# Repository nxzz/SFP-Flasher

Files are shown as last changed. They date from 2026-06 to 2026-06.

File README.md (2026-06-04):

# sfp-eerom-web

ブラウザ（WebHID）から RP2040(Pico) I2C ゲートウェイ経由で SFP モジュールの EEPROM を読み書きするツール一式。
ダンプ／解析、クローン書込（実シリアル番号を維持）、DWDM 波長設定をブラウザだけで行えます。

```
┌────────────┐   WebHID    ┌──────────────┐    I2C     ┌──────────────┐
│  ブラウザ   │ ─ 64B HID ─ │ RP2040(Pico) │ ─ 0x50/   │  SFP module  │
│ (web/)     │   レポート   │  gateway     │   0x51 ── │  EEPROM      │
└────────────┘             └──────────────┘            └──────────────┘
```

## 構成

| ディレクトリ | 内容 |
|---|---|
| [`web/`](web/) | WebHID Web アプリ（Firebase Hosting にデプロイ）。ダンプ／クローン書込／DWDM 設定。詳細は [`web/README.md`](web/README.md) |
| [`device-src/`](device-src/) | RP2040(Pico) ゲートウェイのファームウェア（PlatformIO / arduino-pico コア） |

## WebHID ⇄ I2C プロトコル

64 バイト固定の HID IN/OUT レポートでコマンドをやり取りする汎用 I2C ゲートウェイです。
2 系統の I2C バスに対応します（bus0 = SDA/SCL = IO12/IO13、bus1 = IO26/IO27）。

OUT レポート（ブラウザ → デバイス, 64B）:

| オフセット | 内容 |
|---|---|
| `[0]` seq | 任意のシーケンス番号（応答にそのままエコー） |
| `[1]` cmd | `0x00` PING / `0x01` READ / `0x02` WRITE / `0x03` SCAN |
| `[2]` bus | 0 or 1 |
| `[3]` addr | 7bit I2C アドレス |
| `[4]` reg | レジスタ／オフセット（READ/WRITE 開始位置） |
| `[5]` len | READ=読み出しバイト数 / WRITE=書き込みバイト数 |
| `[6..]` | WRITE データ |

IN レポート（デバイス → ブラウザ, 64B）:

| オフセット | 内容 |
|---|---|
| `[0]` seq | 要求の seq をエコー |
| `[1]` status | `0x00` OK / `0x01` NACK / `0x02` BADARG / `0x03` TOOBIG |
| `[2]` len | 有効データ長 |
| `[3..]` | データ（READ=読み出し値 / SCAN=見つかったアドレス列 / PING=版数） |

- READ は 1 回最大 61 バイト、WRITE は 1 回最大 58 バイト。
- WRITE は 8 バイトページ境界を跨がないよう Web アプリ側で自動分割します（24Cxx 系 EEPROM 対策）。

## デバイスのビルド／書き込み

[PlatformIO](https://platformio.org/) を使用します（arduino-pico / Earle Philhower コア、USB スタックは Adafruit TinyUSB）。

```bash
cd device-src
pio run                 # ビルド
pio run --target upload  # Pico へ書き込み（BOOTSEL でマウント）
```

## Web アプリの実行

```bash
cd web
npx serve .
#  → 表示された http://localhost:xxxx を Chrome / Edge で開く
```

デプロイ手順や機能の詳細は [`web/README.md`](web/README.md) を参照してください。

## 動作要件

- **Chrome / Edge など Chromium 系ブラウザ**（WebHID 対応。iOS Safari は非対応。Android Chrome は対応）
- RP2040(Pico) ゲートウェイ（`device-src/` のファームウェアを書き込んだもの）

## 注意

クローン書込は SFP の EEPROM を上書きします。先に「ダンプ／解析」でバックアップを取得してください。

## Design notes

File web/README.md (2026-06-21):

# SFP Flash Web

ブラウザ（WebHID）から RP2040(Pico) I2C ゲートウェイ経由で SFP の EEPROM を扱う Web アプリ。
スマートフォンにも対応しています。`device/index.html` の WebHID ⇄ I2C プロトコルがベースです。

## 機能

1. **ダンプ / 解析** — SFP(0x50)から 128B を読み、SFF-8472 として解析表示し、`.bin` で保存（`dump.sh` 相当）
2. **クローン書込（実 SN 維持）** — プリセット or アップロードした `.bin` でモジュールを上書きしつつ、
   そのモジュール本来のシリアル番号(0x44–0x53)を維持。チェックサム自動再計算・アンロック・ベリファイ込み（`modsn.sh` 相当）
   - **自動連続書込** — 挿入待ち→書込→抜去待ちを反復し、差し替えるだけで連続クローン（`loop.sh` 相当）
3. **DWDM 波長設定** — チューナブル SFP の ITU グリッドチャンネルを設定（`set-dwdm-ch.py` 相当）
4. **Avago ISP 書換** — `device-avago-isp` ボード（FW v2.x）で Avago/Broadcom 内蔵 ATmega328 を
   ISP(SPI) 経由で直接読み書きする専用タブ（下記参照）

## Avago ISP 書換（device-avago-isp 専用ボード）

Avago/Broadcom 系モジュールは内部 ATmega が EEPROM を読取専用にエミュレートしており、I2C(0x50)からは
書き込めません（隠し mailbox もプログラミングゲートも存在しない個体がある）。そこで本タブは、
`device-avago-isp` ボード（FW v2.x）を使い、内蔵 ATmega328 の EEPROM を **ISP(SPI シリアルプログラミング)** で
**直接**書き換えます。

- **必須**: 専用ファーム `device-avago-isp`（FW v2.x）＋専用配線
  - MOSI=pin4/GP4, SCK=pin5/GP5, MISO=pin9/GP9, /RESET=pin15/GP15, VCC=pin16/3V3, GND=pin1
- HID コマンド: `0x10` ISP_BEGIN（RESET Low→Programming Enable, 応答=signature） /
  `0x11` ISP_XFER（4バイト ISP 命令を全二重転送） / `0x12` ISP_END（RESET 解放→I2C 復帰）
- タブの操作: ① ISP 接続/デバイス確認（signature・lock・fuse） / ② EEPROM 1KB バックアップ /
  ③ ファーム(フラッシュ)32KB ダンプ（読み出しのみ） /
  ④ A0 クローン書込（内部 EEPROM `0x300–0x37F`, 実SN維持・checksum再計算・verify）
- 書込元像の選び方（プリセット / アップロード / 別バスコピー）は **クローン書込タブと同じ操作感**で、
  ISP タブ内に独立して用意してあります。別バスコピーは I2C を使うので **ISP 開始前**に実行してください。
- 内部 EEPROM レイアウト: `0x300–0x37F` = A0(0x50) ページ（実測確定）
- **Chip Erase は使いません**（フラッシュ＝ファームを消さない）。書込前に必ず ② でバックアップを取得。
  ホスト側 CLI 版は `tools/avr_isp.py`、設計詳細は `AVAGO_ISP_DESIGN.md` を参照。

## プリセットの定義（preset-*.json）

書き込み用 EEPROM 像は書込先モジュール種別ごとに5ファイルで定義します。

- SFP（1G/2G/4G・1000BASE-T 等）: [`preset-sfp.json`](preset-sfp.json)（`bin/` 配下に `.bin`）
- SFP+（8G/10G/16G FC・10GBASE 等）: [`preset-sfp-plus.json`](preset-sfp-plus.json)
- SFP28（25G）: [`preset-sfp28.json`](preset-sfp28.json)
- QSFP / QSFP+（40G・SFF-8636 256B）: [`preset-qsfp.json`](preset-qsfp.json)（`bin/qsfp/` 配下に `.bin`）
- QSFP28（100G）: [`preset-qsfp28.json`](preset-qsfp28.json)（`bin/qsfp/` 配下に `.bin`）

`.bin` を置いてエントリを追記するだけで選択肢が増えます（実 SN は書込時に自動維持されるため、ファイルの SN は
問いません）。読込時、各ファイルのエントリには種別（`form`）が自動付与されます（例 preset-sfp→`SFP`、
preset-qsfp28→`QSFP28`）。

UI の **書込先モジュール**セレクタ（`SFP / SFP+` または `QSFP / QSFP28`）を切り替えると、プリセット一覧が
その種別に対応する `form` のみへ自動で絞り込まれます（SFP 系=SFP/SFP+/SFP28、QSFP 系=QSFP/QSFP28）。
バスも種別に連動します（SFP 系=Bus0、QSFP 系=Bus1）。

```json
{
  "presets": [
    { "name": "Finisar FTLX8571D3BCL (10G SR)", "file": "bin/FTLX8571D3BCL.bin", "note": "10G 850nm SR" }
  ]
}
```

> プリセットは `fetch` で読み込むため `https://` / `http://localhost` が必要です。
> `file://` で直接開いた場合は「アップロード」を使うか、ローカルサーバを起動してください。

### bin を自動で追加する（add-preset.py）

`bin` のパスを渡すと、SFF-8472/8636 を読んで**種別を自動判定** → SFP 系は `bin/`・QSFP 系は `bin/qsfp/` へ
**移動** → ベンダー名/型番を抽出して該当 `preset-*.json` に**追記**します（[`add-preset.py`](add-preset.py)）。

```bash
# 1ファイル（または複数・ワイルドカード）を追加
python add-preset.py /path/to/foo.bin
python add-preset.py *.bin

# 判定だけ確認（移動も書込もしない）
python add-preset.py --dry-run /path/to/foo.bin

# 種別や表示名を手動指定（自動判定を上書き）
python add-preset.py --form SFP+ --name "Cisco FOO-10G" /path/to/foo.bin
```

- 種別自動判定は UI と同一ロジック（識別子＋公称ビットレート＋10G互換ビット）。誤判定時は `--form` で上書き。
- 表示名は既定で「ベンダー 型番」。`--name` で上書き可（複数 bin 指定時は不可）。
- 既に同じ `file` パスが登録済みならスキップします。実 SN は書込時に UI が維持するため bin の SN は問いません。

## 動作要件

- **Chrome / Edge など Chromium 系ブラウザ**（WebHID 対応。iOS Safari は非対応）
- RP2040(Pico) ゲートウェイ（ファーム `device/sfp-gateway.uf2`、プロトコル `device/USB_PROTOCOL.md`）

## ローカル実行

```bash
npx serve .
#  → 表示された http://localhost:xxxx を Chrome で開く
```

## Firebase Hosting へのデプロイ

このディレクトリ（`web/`）がそのままデプロイ単位です。

```bash
npm install -g firebase-tools
firebase login
# .firebaserc の "YOUR_FIREBASE_PROJECT_ID" を実プロジェクト ID に置換してから:
cd web
firebase deploy --only hosting
```

## 注意

- クローン書込は EEPROM を上書きします。先に「ダンプ / 解析」でバックアップを取得してください。
- WRITE は 1 回最大 56 バイト、8 バイトページ境界を跨がないよう自動分割します（24Cxx 系 EEPROM 対策）。

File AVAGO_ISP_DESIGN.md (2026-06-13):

# Avago(AVR内蔵)SFP — Pico経由ISPでEEPROMを書き換える設計

## 0. 背景（検証済みの前提）

I2C(0x50/0x51)経由ではこの個体は書けない、と実機＋ファーム解析で確定済み：

- 対象モジュール: ラベル BROCADE 57-1000117-01 / OEM実体 `AFBR-57D9AMZ-BR1`（= Avago/Broadcom, **ATmega328内蔵**）
- 0x50への書込みは **status=OK でも値が変わらない**（AVRが読取専用エミュレート）。SFFパスワード(0/Finisar)は無効。
- 隠しmailbox `0x58/0x5A` は **NACK**（ハンドラ無効）。有効化条件は内部EEPROM `0x01FF==0x55`（起動時にRAM `0x0336` へ複製、`cpi 0x55` で判定 ＝ ファームで確認済み）。
- ファームに **SPM命令なし** ＝ I2C/シリアルのブートローダ無し。**再書込みはISP(SPI)のみ**。

→ 結論：**内蔵ATmega328のEEPROMをISPで直接書く**。これなら0x55ゲートの鶏卵問題を完全に回避できる。

---

## 1. 全体像

```
                      ┌─ I2Cモード: SFP pin4/5 = SDA/SCL (現状のゲートウェイ)
 Pico (RP2040) ──┤
                      └─ ISPモード: pin4=MOSI pin5=SCK pin9=MISO pin15=RESET (新規)
```

Picoファームに「ISPモード」を追加し、同じUSB-HID(64B)枠でISP用コマンドを足す。
ホスト側(Python)がAVR ISPプロトコルを実装して、EEPROMの吸出し/書込み/照合を行う。

SCK/MOSI は**現状のI2C配線(GPIO12/13)を流用**できる（SFP pin4=SDA=MOSI, pin5=SCL=SCK）。
追加で必要な物理配線は **MISOとRESETの2本だけ**。

---

## 2. 配線（専用ボード: RP2040 ↔ SFPエッジコネクタ）

**VCC/GND 以外は「SFPピン番号 = RP2040 GPIO番号」**で結線した専用ボード。

| 信号 | RP2040 GPIO | SFPピン | 備考 |
|---|---|---|---|
| MOSI | **GP4** | pin4 | I2C bus0 SDA と共用（データ線） |
| SCK  | **GP5** | pin5 | I2C bus0 SCL と共用（クロック線） |
| MISO | **GP9** | pin9 | 入力。成否確認用（無くてもブラインド書込可） |
| /RESET | **GP15** | pin15 | active-low、ISP中ずっとLow |
| VCC 3.3V | 3V3(OUT) | pin16 | モジュール給電 |
| GND | GND | pin1 | コモングラウンド必須 |

> SDA↔MOSI(GP4) / SCL↔SCK(GP5) は役割が一致するので相乗り可。通常時 PB3/PB4/PB5 は
> Hi-Z 入力（ファームで DDRB=0 を確認済み）なので I2C 動作と衝突しない。
> ファームは ISP モードで GP4/5 をビットバングに切替え、ISP_END で I2C(bus0=4/5) に戻す。

ISP突入時は **先にRESETをLow** にしてからSPIを叩く。RESET Lowの間AVRは全ポートをHi-Zにするので、
SCK/MOSIがI2Cプルアップと衝突しない。

---

## 3. ISP突入シーケンス（AVRシリアルプログラミング）

1. SCK = Low（アイドル）にしておく
2. /RESET = Low（GPIO15 Low）
3. 20ms以上待つ
4. **Programming Enable** を送信：`0xAC 0x53 0x00 0x00`
   - 3バイト目の応答エコーが `0x53` なら突入成功。違えばRESETをトグルしてリトライ。
5. 終了時：/RESET = High に戻す（GPIO15開放）→ AVR通常起動 → I2Cに復帰

SCK周波数は **ターゲットクロックの1/4未満**。SFPのAVRは内蔵8MHz想定なので **100–250kHz** で安全側。
Picoのビットバングで十分。

---

## 4. 使うAVR ISPコマンド（4バイト/コマンド, MISO上の応答を読む）

| 操作 | バイト列 | 戻り |
|---|---|---|
| Programming Enable | `AC 53 00 00` | 3バイト目に`53`エコー |
| Read Signature | `30 00 0x 00` (x=0/1/2) | ATmega328=`1E 95 14` / 328P=`1E 95 0F` |
| Read Lock bits | `58 00 00 00` | lockバイト |
| Read Fuse(low/high/ext) | `50 00 00 00` / `58 08 00 00` / `50 08 00 00` | 各fuse |
| **Read EEPROM** 1byte | `A0 00 ad 00` | data（ad=8bit, 1KBなら上位は別途） |
| **Write EEPROM** 1byte | `C0 00 ad dd` | — (書込後 約4ms待つ or RDY/BSYポーリング `F0 00 00 00`) |
| Chip Erase | `AC 80 00 00` | フラッシュ＋EEPROM全消去（**通常は使わない**） |

> ATmega328のEEPROMは1KB(アドレス10bit)。`A0/C0` の上位アドレスビットは2バイト目に載る形式に注意
> （ホスト側で `addr` を 16bit として上位/下位に展開）。バイト単位R/Wで十分（ページ書込みは任意の最適化）。

---

## 5. Picoファーム拡張のインタフェース（device-src/src/main.cpp）

既存の64B HID枠（seq/cmd/...）にISP系を追加。I2Cコマンド(0x00–0x03)はそのまま。

| `cmd` | 名前 | OUT引数 | 動作 / IN応答 |
|---|---|---|---|
| `0x10` | ISP_BEGIN | — | GPIO12/13をWireから切離しSPIビットバングに切替、RESET Low、Programming Enable送信。`data[0]`=成功可否、`data[1..3]`=signature |
| `0x11` | ISP_XFER | `len`=4, `data[6..9]`=4バイト | 4バイトSPIトランザクションを実行し、4バイトの応答を `data[0..3]` で返す（汎用。EEPROM R/Wも全部これで表現） |
| `0x12` | ISP_END | — | RESET High、GPIO12/13をWire(I2C)に復帰 |

設計ポイント：
- **モード排他**：ISP_BEGIN中はI2C(Wire)を `end()`、ISP_END で `Wire.begin()` し直す。GP4/5の機能切替を明示。
- ISP_XFER は薄い「4バイト出して4バイト受ける」だけ。AVR ISPの賢さは全部ホスト側に置く（ファームを単純・汎用に保つ）。
- 速度最適化が要るなら後で `0x13 ISP_READ_EEPROM_BLOCK`（連続n byte吸出し）を足せるが、まずはXFERのみでよい。

---

## 6. ホスト側 Python（tools/avr_isp.py 予定）の責務

`tools/pico_i2c.py` と同じHIDトランスポートを再利用。`Pico` クラスに ISP_BEGIN/XFER/END を足すだけ。

- `enter()/exit()`、`signature()`、`read_lock()/read_fuses()`
- `eeprom_read(addr,n)` / `eeprom_write(addr,bytes)`（XFERの組合せ＋書込後ポーリング）
- `dump_eeprom()` … 1KB全吸出し
- `discover_layout()` … 吸い出したEEPROMと、I2Cで読んだ 0x50/0x51 ダンプ(`pico_i2c.py`)を**バイト照合**して
  「内部EEPROMのどのオフセットが 0x50/0x51 のどこか」を**実測で確定**（下記§7の仮説を裏取り）
- `write_image()` … 改変済み 0x50/0x51 像を対応オフセットへ書込み → 再吸出しでベリファイ → I2C再読込で最終確認

---

## 7. 内部EEPROMレイアウト仮説（ISP吸出しで確定する）

`0x01FF` がゲート＝A2ページ末尾、という事実から：

| 内部EEPROM | I2C側 | 根拠 |
|---|---|---|
| `0x000–0x0FF` | A0 (0x50) 0x00–0xFF | ― |
| `0x100–0x1FF` | A2 (0x51) 0x00–0xFF | `0x1FF`=ゲート=A2末尾と整合 / mailbox 0x5B「128B→A2:0x80-0xFF」とも整合 |
| `0x200–0x3FF` | DDM校正・予備 | ― |

照合で確定後、書きたいのは基本 `0x000–0x0FF`（A0:ベンダ/PN/SN/波長/チェックサム0x3F）と
必要なら `0x100–0x1FF`（A2:0x5F/0x95等チェックサム）。**SN維持クローン**なら 0x44–0x5B を残して上書き。

---

## 8. 作業ワークフロー（実装済み）

1. 専用ボード配線（§2）。pin15→GP15 を RESET として駆動できることを確認。
2. 専用ファームを書込み：`cd device-avago-isp && pio run -t upload`（BOOTSELでマウント）。既存 `device-src` は無改変。
3. `python tools/avr_isp.py` … PING/signature/lock/fuse 確認（ロック時はここで判明）
4. `python tools/avr_isp.py --backup` … EEPROM 1KB全吸出し → `avr_eeprom_backup.bin`（**必須バックアップ**）
5. `python tools/avr_isp.py --set` … `EEPROM[0x01FF]=0x55` を書込み（元値は表示されるので控える）
6. **電源再投入** → `python tools/pico_i2c.py 0` で `0x58` が出れば成功（プログラミングモード）
7. 以降は I2C mailbox(0x58) で EEPROM を読み書き（Web版「Avago Mailbox」タブ or pico_i2c.py 拡張）
8. 仕上げに `0x01FF` を最終値へ（`--restore 0xNN`、またはmailbox）→ 電源再投入で完成

---

## 9. リスクと注意

- **ロックビット**：Cisco/Avago量産品はフラッシュ読出禁止のことあり。ただし `Cisco_AVAGO_10GSC_farm.BIN`(32KB吸出し)が存在＝吸出し元はロック無し。実機もロック無しならEEPROM R/W可。ロック時は §3-4 のsignature/lock読みで判明し、Chip Erase以外で解除不可（Eraseはフラッシュも消える＝モジュール死亡。やらない）。
- **Chip Erase は使わない**（フラッシュ＝AVRファームまで消える）。EEPROMは `C0` で消去不要の上書きが可能。`avr_isp.py` は Chip Erase コマンドを実装していない。
- **必ず先に全EEPROMをバックアップ**（`--backup`）してから書く。
- 電圧は3.3V系で統一。5Vは使わない。
- ISP中はI2C不可（GP4/5を占有）。ISP_BEGIN/ISP_END でフェーズを分ける。
- `avr_isp.py` は既定が**ドライラン**。書込みは `--set` を明示したときだけ。

---

## 10. ファーム & ツール

- **`device-avago-isp/`** … Avago専用ファーム（FW v2.0）。I2Cゲートウェイ＋ISP 3コマンド。**既存 `device-src` は無改変**。
- `tools/avr_isp.py` … ISP ホスト（signature/fuse/lock、EEPROM R/W、`--set`でゲート書込、`--backup`で吸出し）
- `tools/pico_i2c.py` … I2Cダンプ/検証・mailbox前後の確認
- `tools/avr_dis.py` … ファーム逆アセンブラ（ゲート 0x01FF→0x0336 / 0x55 判定の解析に使用済み）

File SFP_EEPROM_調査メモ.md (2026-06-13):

# Avago/Broadcom SFP ファーム解析メモ（avr_flash_dump.bin）

対象: `avr_flash_dump.bin`（32768 byte = 16K word）
目的: i2c から内部 EEPROM を書き換える / **型番(Vendor PN)を変更する**

---

## 1. ハードウェア / ファーム構造（確定）

| 項目 | 結果 |
|---|---|
| MCU | **ATmega328P**（Flash 32KB / 内蔵 EEPROM 1KB） |
| アーキ | `avr-objdump -m avr:5` で正しくデコード（reset = `jmp 0x46fe`） |
| i2c 方式 | **全てビットバンギング**（HW TWI=0xB8–0xBC へのアクセス皆無）。INT0(EIMSK=0x1d/EIFR=0x1c) で SCL 検出 |
| データの真の保管先 | **ATmega328P の内蔵 EEPROM**（avr-libc 標準ドライバを確認） |

### 確認した主要ルーチン
- `0x44c4` = `eeprom_write_byte`（EEARH/EEARL/EEDR→EEMPE→EEPE）
- `0x44d4` / `0x44e4` = `eeprom_read_byte`
- `0x438c` = **i2c マスター書き込み**（start=0x4736, sendbyte=0x419a, ack=0x41e8, stop=0x4224）→ 外部デバイス 0xA0/0xB0 等へ
- `0x4326` = ページ(A2h)シャドウ書き込み API、`0x3cf6` = ホストからの A2h 書き込みハンドラ

### データフロー
```
[ATmega328P 内蔵EEPROM] --(起動/更新時にコピー)--> [外部0xA0 EEPROM = ホストが読むA0h]
        ↑真の保管先                                       ↑被参照コピー
```
内蔵 EEPROM が「正本」。A0h ページは内蔵 EEPROM から書き出される。

---

## 2. 書き込み可否マップ（ホスト i2c 経由）

ホスト書き込みハンドラ(0x3cf6–0x3d96)解析結果：受信バイトは RAM シャドウには反映されるが、
**内蔵 EEPROM への永続化はオフセットを `0x80 ≤ off < 0xF8` でゲート**（`cpi 0x80`/`cpi 0xF8`）。

| 領域 | i2c addr | 書込 | 永続化 | 備考 |
|---|---|---|---|---|
| A2h 0x80–0xF7 | 0x51 | ✅ | ✅ | **ユーザー領域。ノーガードで書ける** |
| A2h 0x00–0x7F / 0xF8–0xFF | 0x51 | △RAMのみ | ❌ | DDM/閾値。リセットで復帰 |
| A0h（ベンダ名/**型番**等） | 0x50 | ホスト書込ハンドラ無し | ❌ | 内蔵EEPROMから書き出される＝実質read-only |

### パスワード
**無し。** SFF-8472 のパスワードオフセット(0x7B–0x7E)比較も4バイトキー照合も存在しない。
ゲートは「オフセット範囲」のみ。

---

## 3. 型番(Vendor PN)変更について ★本命

### 結論: ホスト i2c（前回の選択肢 C 等）では型番は変えられない
- 型番 = **A0h オフセット 0x28–0x37（40–55, 16文字ASCII）** + Rev 0x38–0x3B（SFF-8079）
- 選択肢 C が書けるのは A2h 0x80–0xF7 → **別ページなので無関係**
- A0h にはホスト側スレーブ書込ハンドラが存在しない。仮に外部0xA0 EEPROMを直接書けても、内蔵EEPROMから再コピーされ上書きされる

### 確実な方法: ISP で内蔵 EEPROM を直接書き換える
内蔵 EEPROM → A0h の線形マッピングを確定済み：

> **A0h オフセット N  ↔  内蔵 EEPROM アドレス 0x0300 + N**
> （site1: EEPROM[0x300..0x37F]→A0h[0x00..0x7F]、site2: EEPROM[0x380..0x3FF]→A0h[0x80..0xFF]）

したがって内蔵 EEPROM 上では：

| A0h 内容 | A0h offset | 内蔵EEPROM addr |
|---|---|---|
| Vendor name | 0x14–0x23 | 0x0314–0x0323 |
| **Vendor PN（型番）** | **0x28–0x37** | **0x0328–0x0337** |
| Vendor Rev | 0x38–0x3B | 0x0338–0x033B |
| **CC_BASE チェックサム** | 0x3F | **0x033F** |

#### 手順
```bash
sudo apt install avrdude
# USBasp 等を ATmega328P の ISP端子(MISO/MOSI/SCK/RESET/VCC/GND)へ接続

# 1) バックアップ（必須）
avrdude -c usbasp -p m328p -U eeprom:r:eeprom_backup.bin:r
avrdude -c usbasp -p m328p -U flash:r:flash_backup.bin:r

# 2) eeprom_backup.bin の 0x0328–0x0337 を新しい型番(ASCII, 16byte, 余りは空白0x20)に編集
# 3) CC_BASE 再計算: A0h[0x3F] = (A0h[0x00..0x3E] の総和) & 0xFF
#    = 内蔵EEPROM[0x0300..0x033E] の総和 & 0xFF を [0x033F] に書く
#    ※再計算しないとホスト/NICがモジュールを弾く可能性

# 4) 書き戻し
avrdude -c usbasp -p m328p -U eeprom:w:eeprom_new.bin:r
```
注意: lock bit で保護されていると read/write 不可の場合あり（その時は fuse 確認）。

---

## 4. 実機で i2c 書き込みを試す場合（ユーザー領域のみ）
```bash
sudo apt install i2c-tools
i2cdetect -y <bus>            # 0x50,0x51 確認
i2cdump  -y <bus> 0x51        # バックアップ
i2cset   -y <bus> 0x51 0x80 0xAB   # A2h 0x80–0xF7 のみ永続
i2cget   -y <bus> 0x51 0x80
```

---

## 5. ファーム全体の役割（推定）

reset(0x46fe): SP/フレームポインタ初期化 → 自己チェック(0x4764) → main(0x475e) 無限ループ。
ATmega328P 自身の ADC/USART/SPI は未使用（アナログは外部ICに委譲）。

最頻出コール: `0x438c`(i2cマスター書込) **93回**, `0x44d4`(内蔵EEPROM読) **49回**, 固定小数点演算群(`0x4744`乗算, `0x35c2/0x366a/0x372c`)。

役割まとめ:
1. **ホスト向け i2c スレーブ**(ビットバング, INT0/SCL): A0h/A2h を提供
2. **i2c マスター・オーケストレータ**: 外部アナログ IC を制御
   | 外部addr | 7bit | 回数 | 推定役割 |
   |---|---|---|---|
   | **0xB0** | 0x58 | 96 | アナログ制御IC(レーザ駆動/変調/RX監視)。多数レジスタ設定 |
   | 0xA8 | 0x54 | 12 | 補助デバイス(追加EEPROM/センサ) |
   | 0xA2/0xA0 | 0x51/0x50 | 23/3 | ページEEPROMの被参照コピー書出し |
3. **内蔵EEPROMから較正値読出し** → 0xB0 IC設定 & A0h/A2hページ生成（内蔵EEPROM=正本）
4. **DDM**: 0xB0から温度/電圧/TXbias/TX・RXパワーの生値読込→固定小数点でスケーリング→A2h 0x60-0x6F に書込→閾値比較でアラーム/警告フラグ(0x70+)生成（∴0x00-0x7Fは常時上書き=非永続）
5. **ウォッチドッグ**: `wdr`を98箇所で蹴る

> 一言: **「ホストにSFPとして振る舞うi2cスレーブ」兼「外部アナログIC(0x58)を制御するi2cマスター」で、内蔵EEPROMの較正値でレーザ制御＋DDM監視を行うSFPコントローラ。**

## 6. 改造ファーム：ISP一回で「i2cから型番書換」可能化（実装済み）

方針: **ユーザー領域(A2h 0x80–0xF7)は未使用**なので、そのままの素通しマップで A0h へ振り替える（モードフラグ/コマンド不要、オフセット計算のみ）。

### マッピング
> **A2h(0x51) オフセット (0x80 + k) への i2c 書込 → 内蔵EEPROM[0x300 + k] = A0h[k]**（k=0x00..0x77）

| A0h 内容 | A0h off | 書込先 i2c | (0x51) offset |
|---|---|---|---|
| Vendor name | 0x14–0x23 | 0x51 | 0x94–0xA3 |
| **Vendor PN（型番）** | 0x28–0x37 | 0x51 | **0xA8–0xB7** |
| Vendor Rev | 0x38–0x3B | 0x51 | 0xB8–0xBB |
| **CC_BASE** | 0x3F | 0x51 | **0xBF** |
| CC_EXT | 0x5F | 0x51 | 0xDF |

### パッチ内容（12バイト, `make_patch.py` で生成）
| アドレス | 元 | 改 |
|---|---|---|
| 0x3d80 | `call 0x44c4` | `call 0x4800`（フック） |
| 0x4800 | (空) | `subi r16,0x80` |
| 0x4802 | (空) | `ldi r17,0x03` |
| 0x4804 | (空) | `jmp 0x44c4`（eeprom_write 末尾Jmp） |

出力: `avr_flash_patched.bin`

### 焼き込み（ISP・1回のみ）
```bash
avrdude -c usbasp -p m328p -U flash:r:flash_backup.bin:r     # 退避(必須)
avrdude -c usbasp -p m328p -U eeprom:r:eeprom_backup.bin:r
avrdude -c usbasp -p m328p -U flash:w:avr_flash_patched.bin:r  # 改造ファーム書込
# ※EEPROMは触らない＝現行の型番/較正はそのまま温存
```

### 以降の型番変更（i2cのみ・ISP不要）
1. PN(0x28–0x37, 16byte ASCII, 余りは空白0x20) を i2c 0x51 の 0xA8–0xB7 へ書く
2. **CC_BASE 再計算**: `A0h[0x3F] = Σ A0h[0x00..0x3E] & 0xFF` を 0x51 の 0xBF へ書く（host側で計算）
3. **SFPを抜き挿し（電源再投入）** → 起動時に内蔵EEPROM→A0hが再生成され新型番反映

→ 付属 `recode_pn.sh <bus> "<新型番>"` が PN書込＋CC_BASE再計算を自動化。

### 注意 / フェイルセーフ
- A2h ユーザー領域(0x80–0xF7)は本改造で A0h 編集専用になる（未使用前提）
- CC_BASE 不一致だとホスト/NICがモジュールを弾く可能性 → 必ず再計算
- 失敗しても flash/eeprom バックアップから ISP で復旧可

## 7. 解析環境
- `avr-objdump -D -b binary -m avr:5 avr_flash_dump.bin > fw.asm`
- i2c-tools / avrdude は apt で導入

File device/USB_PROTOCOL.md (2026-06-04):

# SFP EEPROM ゲートウェイ USB / WebHID 仕様書

ブラウザ（WebHID）から Raspberry Pi Pico (RP2040) を経由して、SFP の
I2C EEPROM を読み書きするためのプロトコル仕様。

- ファーム: `c:\Users\netwing\Documents\PlatformIO\Projects\sfp-eeprom-web\src\main.cpp`
- フロント: `index.html`（同フォルダ）
- USB スタック: Adafruit TinyUSB（`-DUSE_TINYUSB`）

---

## 1. USB デバイス構成

複合デバイス（Composite）。

| インタフェース | 用途 |
|---|---|
| **HID**（vendor-defined） | コマンド／応答チャネル（本仕様の対象） |
| **CDC**（仮想シリアル） | デバッグログ出力（115200 bps、任意） |

### HID ディスクリプタ

- レポートディスクリプタ: `TUD_HID_REPORT_DESC_GENERIC_INOUT(64)`
- **Usage Page: `0xFF00`**（ベンダ定義）, Usage: `0x01`
- **Report ID なし**（= レポート ID `0`）
- **Input レポート 64 バイト固定**（デバイス → ホスト）
- **Output レポート 64 バイト固定**（ホスト → デバイス）
- Poll interval: 2 ms

### WebHID からの接続

Usage Page でフィルタするため VID/PID に依存しない。

```js
const devices = await navigator.hid.requestDevice({
  filters: [{ usagePage: 0xFF00 }]
});
const device = devices[0];
await device.open();
device.addEventListener("inputreport", onInputReport);
// 送信は reportId = 0、64バイト固定
await device.sendReport(0, new Uint8Array(64));
```

> WebHID は secure context が必要。`http://localhost` または `https://`、
> および Chrome では `file://` でも利用可能。

---

## 2. レポートフォーマット

すべて 64 バイト固定。未使用領域は `0` 埋め。

### 2.1 OUT（要求）ホスト → デバイス

| オフセット | 名前 | 説明 |
|---|---|---|
| 0 | `seq`  | シーケンス番号。応答にそのまま返る（要求と応答の対応付けに使用） |
| 1 | `cmd`  | コマンド（§3） |
| 2 | `bus`  | I2C バス: `0` or `1`（§4） |
| 3 | `addr` | 7bit I2C アドレス（例: SFP は `0x50` / `0x51`） |
| 4 | `reg`  | レジスタ／オフセット（READ/WRITE の開始位置、0–255） |
| 5 | `len`  | データ長（READ=読み出し数 / WRITE=書き込み数） |
| 6–63 | `data` | WRITE データ（最大 58 バイト） |

### 2.2 IN（応答）デバイス → ホスト

| オフセット | 名前 | 説明 |
|---|---|---|
| 0 | `seq` | 要求の `seq` をエコー |
| 1 | `status` | ステータス（§5） |
| 2 | `len` | 有効データ長 |
| 3–63 | `data` | データ（READ=読み値 / SCAN=検出アドレス列 / PING=版数） |

---

## 3. コマンド

| `cmd` | 名前 | 動作 | 応答 `data` |
|---|---|---|---|
| `0x00` | **PING**  | 疎通確認 | `[0]`=FW major, `[1]`=FW minor（`len`=2） |
| `0x01` | **READ**  | `addr` の `reg` から `len` バイト読む（reg ポインタ書込→read） | 読み出しバイト列（`len` バイト） |
| `0x02` | **WRITE** | `addr` の `reg` から `data` を `len` バイト書く | なし（`len`=0） |
| `0x03` | **SCAN**  | `bus` 上の `0x08`–`0x77` を走査 | 検出アドレス列（`len`=件数） |

### 動作詳細

- **READ**: `beginTransmission(addr) → write(reg) → endTransmission(STOP) → requestFrom(addr,len)`。
  指定数を取得できなければ `NACK`。
- **WRITE**: `beginTransmission(addr) → write(reg) → write(data...) → endTransmission(STOP)`。
  完了後 **6 ms** 待つ（EEPROM 書き込みサイクル対策。レジスタ系デバイスには無害）。
- **SCAN**: 各アドレスへ空トランザクションを送り、ACK が返ったものを列挙。

---

## 4. バス割り当て（RP2040）

| `bus` | ペリフェラル | コード | SDA | SCL |
|---|---|---|-----|-----|
| `0` | i2c0 | `Wire`  | GPIO12 | GPIO13 |
| `1` | i2c1 | `Wire1` | GPIO26 | GPIO27 |

クロック: 両バスとも 100 kHz。

---

## 5. ステータスコード

| 値 | 名前 | 意味 |
|----|---|---|
| `0x00` | OK | 成功 |
| `0x01` | NACK | デバイス無応答 / 期待バイト数に届かず |
| `0x02` | BADARG | 不正な引数（例: `bus > 1`） |
| `0x03` | TOOBIG | `len` が上限超過 |

---

## 6. サイズ上限と分割

| 項目 | 値 | 由来 |
|---|-----|---|
| 1 回の READ 最大 | **61 バイト** | `64 − 3`（応答ヘッダ） |
| 1 回の WRITE 最大 | **58 バイト** | `64 − 6`（要求ヘッダ） |

フロント側（`index.html`）の実装上限と分割方針:

- READ: **60 バイト/回**でチャンク分割し、`reg` を進めて連結。
- WRITE: **56 バイト/回** かつ **8 バイトページ境界**を跨がないよう分割
  （24Cxx 系 EEPROM のページ書き込み対策）。

`reg` は 8bit のため **オフセットは 0–255**。SFP の 256 バイトページ内で完結する。
A0h（0x50）/ A2h（0x51）のページ切替が要る場合はアドレス自体を変える。

---

## 7. 通信シーケンス例

### PING
```
OUT: seq=01 cmd=00 ...
IN : seq=01 status=00 len=02 data=[01 00]   // FW v1.0
```

### SFP 基本情報を 16 バイト読む（0x50, offset 0x14 = Vendor name 先頭）
```
OUT: seq=02 cmd=01 bus=00 addr=50 reg=14 len=10
IN : seq=02 status=00 len=10 data=[... ASCII ...]
```

### 1 バイト書き込み（0x50, offset 0x7F に 0xAB）
```
OUT: seq=03 cmd=02 bus=00 addr=50 reg=7F len=01 data=[AB]
IN : seq=03 status=00 len=00
```

### バススキャン（bus0）
```
OUT: seq=04 cmd=03 bus=00 ...
IN : seq=04 status=00 len=02 data=[50 51]    // 0x50, 0x51 検出
```

---

## 8. 注意事項

- ホストは **1 要求 → 1 応答** を直列に行うこと。ファームは応答未送信中の新規
  OUT レポートを無視する（単一スロット）。
- 応答タイムアウトはフロント側で 2000 ms 推奨。
- SFP の EEPROM は書き込み保護領域・パスワード保護領域がある場合がある
  （A0h の一部、A2h の制御/パスワード領域など）。WRITE 失敗時は `NACK` が返る。

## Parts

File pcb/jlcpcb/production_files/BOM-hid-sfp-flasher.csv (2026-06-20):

Comment | Designator | Footprint | LCSC | Quantity
0.1u | C10,C11,C12,C13,C14,C15,C16,C18,C3,C6,C7 | C_0402_1005Metric | C1525 | 11
10k | R17,R18,R19,R20 | R_0402_1005Metric | C25744 | 4
10u | C5 | C_0603_1608Metric | C19702 | 1
15k | R6 | R_0603_1608Metric | C22809 | 1
1k | R7,R8 | R_0402_1005Metric | C11702 | 2
1u | C8,C9 | C_0402_1005Metric | C52923 | 2
2.2u 3A | L1 | CMLW4030S2R2MST | C431273 | 1
30pF | C1,C2 | C_0603_1608Metric | C1658 | 2
33 | R3,R4 | R_0402_1005Metric | C25105 | 2
4.7u | C4 | C_0603_1608Metric | C19666 | 1
5.1k | R1,R2 | R_0402_1005Metric | C25905 | 2
68k | R5 | R_0603_1608Metric | C23231 | 1
HC-TYPE-C-16P-01A-O | USB1 | USB-C-SMD_G-SWITCH_GT-USB-7010EN | C2997434 | 1
PSRV05-4MR6T1G | D1 | SOT-23-6_L2.9-W1.6-P0.95-LS2.8-BL | C2936987 | 1
QSFP28 38PIN 49091-01M311 | U4 | CONN-SMD_38P-P0.80_TE_1551920-2 | C50159077 | 1
RESET | SW2 | SW_SPST_PTS810 | C470427 | 1
RP2040 | U1 | LQFN-56_L7.0-W7.0-P0.4-EP | C2040 | 1
SFP+ | J1 | SFP20P | C42418480 | 1
SMD-3225_4P12M20PF10PPM | X1 | CRYSTAL-SMD_4P-L3.2-W2.5-BL | C133334 | 1
SMD0805B050TF | F1 | F0805 | C269104 | 1
TLV62569DBV | U3 | SOT-23-5 | C141836 | 1
USB_BOOT | SW1 | SW_SPST_PTS810 | C470427 | 1
W25Q16JVUXIQ | U2 | USON-8_L3.0-W2.0-P0.50-BL-EP | C2843335 | 1

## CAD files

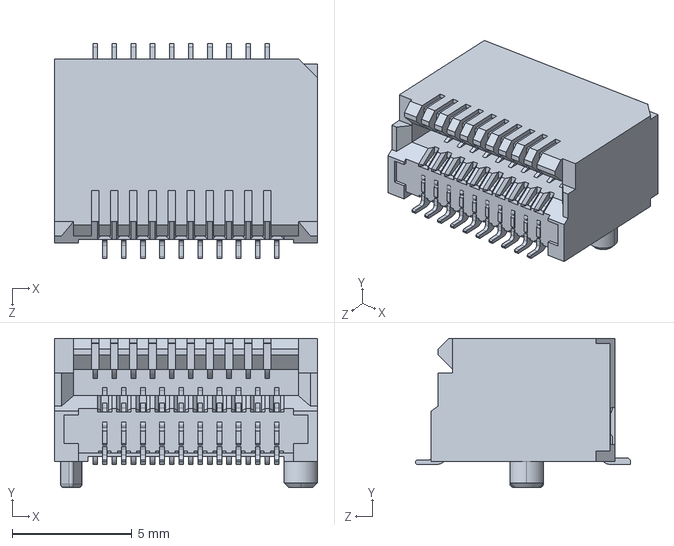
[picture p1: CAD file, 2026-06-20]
pcb/SFP20P/SFP20P SFP&SFP &SFP28 1X1连接器 模型3D.STEP
11.0 x 6.25 x 8.99 mm

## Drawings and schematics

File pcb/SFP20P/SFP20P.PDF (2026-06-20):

### MECHANICAL DIMENSION

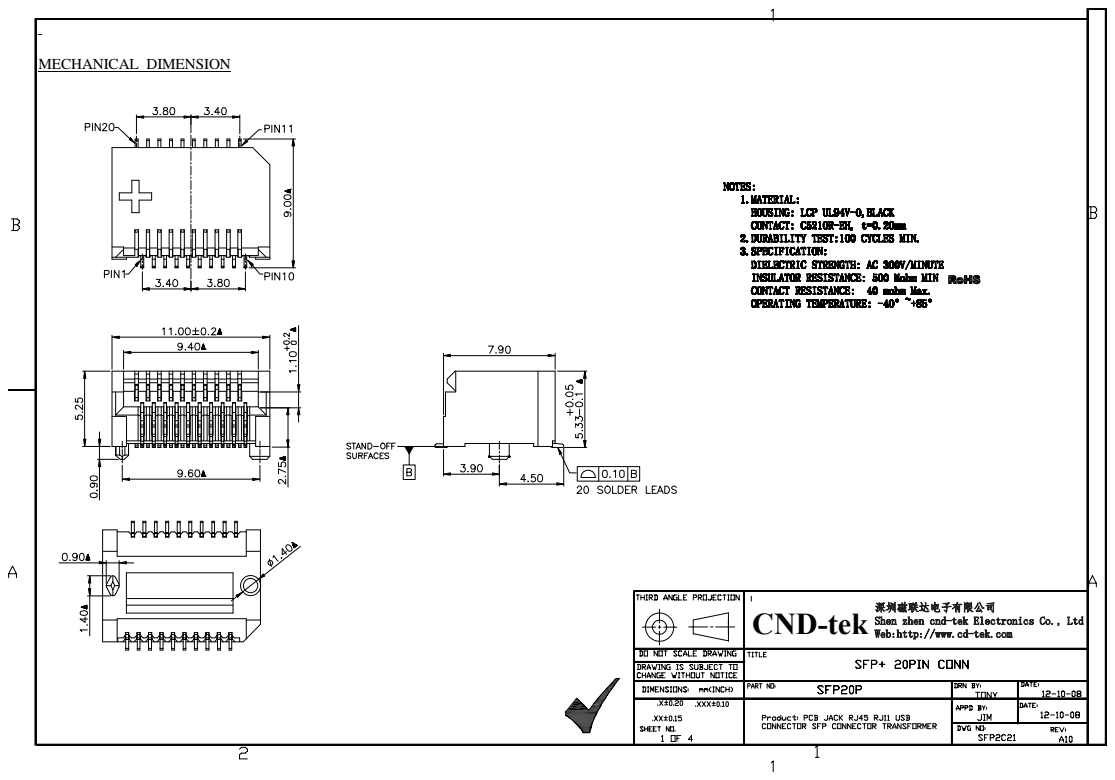
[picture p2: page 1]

深圳磁联达电子有限公司 Shen zhen cnd-tek Electronics Co., Ltd CND-tek Web:http://www.cd-tek.com

SFP+ 20PIN CONN
SFP20P

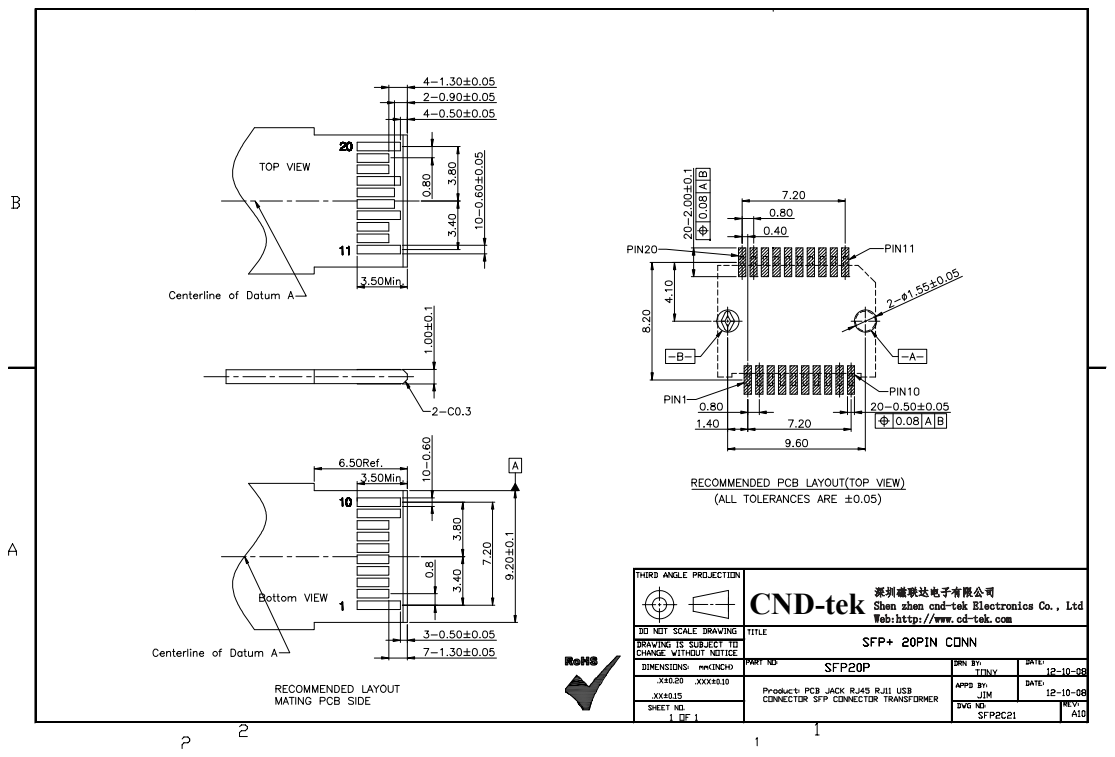
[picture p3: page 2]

Shen zhen cnd-tek Electronics Co., Ltd CND-tek Web:http://www.cd-tek.com 深圳磁联达电子有限公司

SFP+ 20PIN CONN
SFP20P

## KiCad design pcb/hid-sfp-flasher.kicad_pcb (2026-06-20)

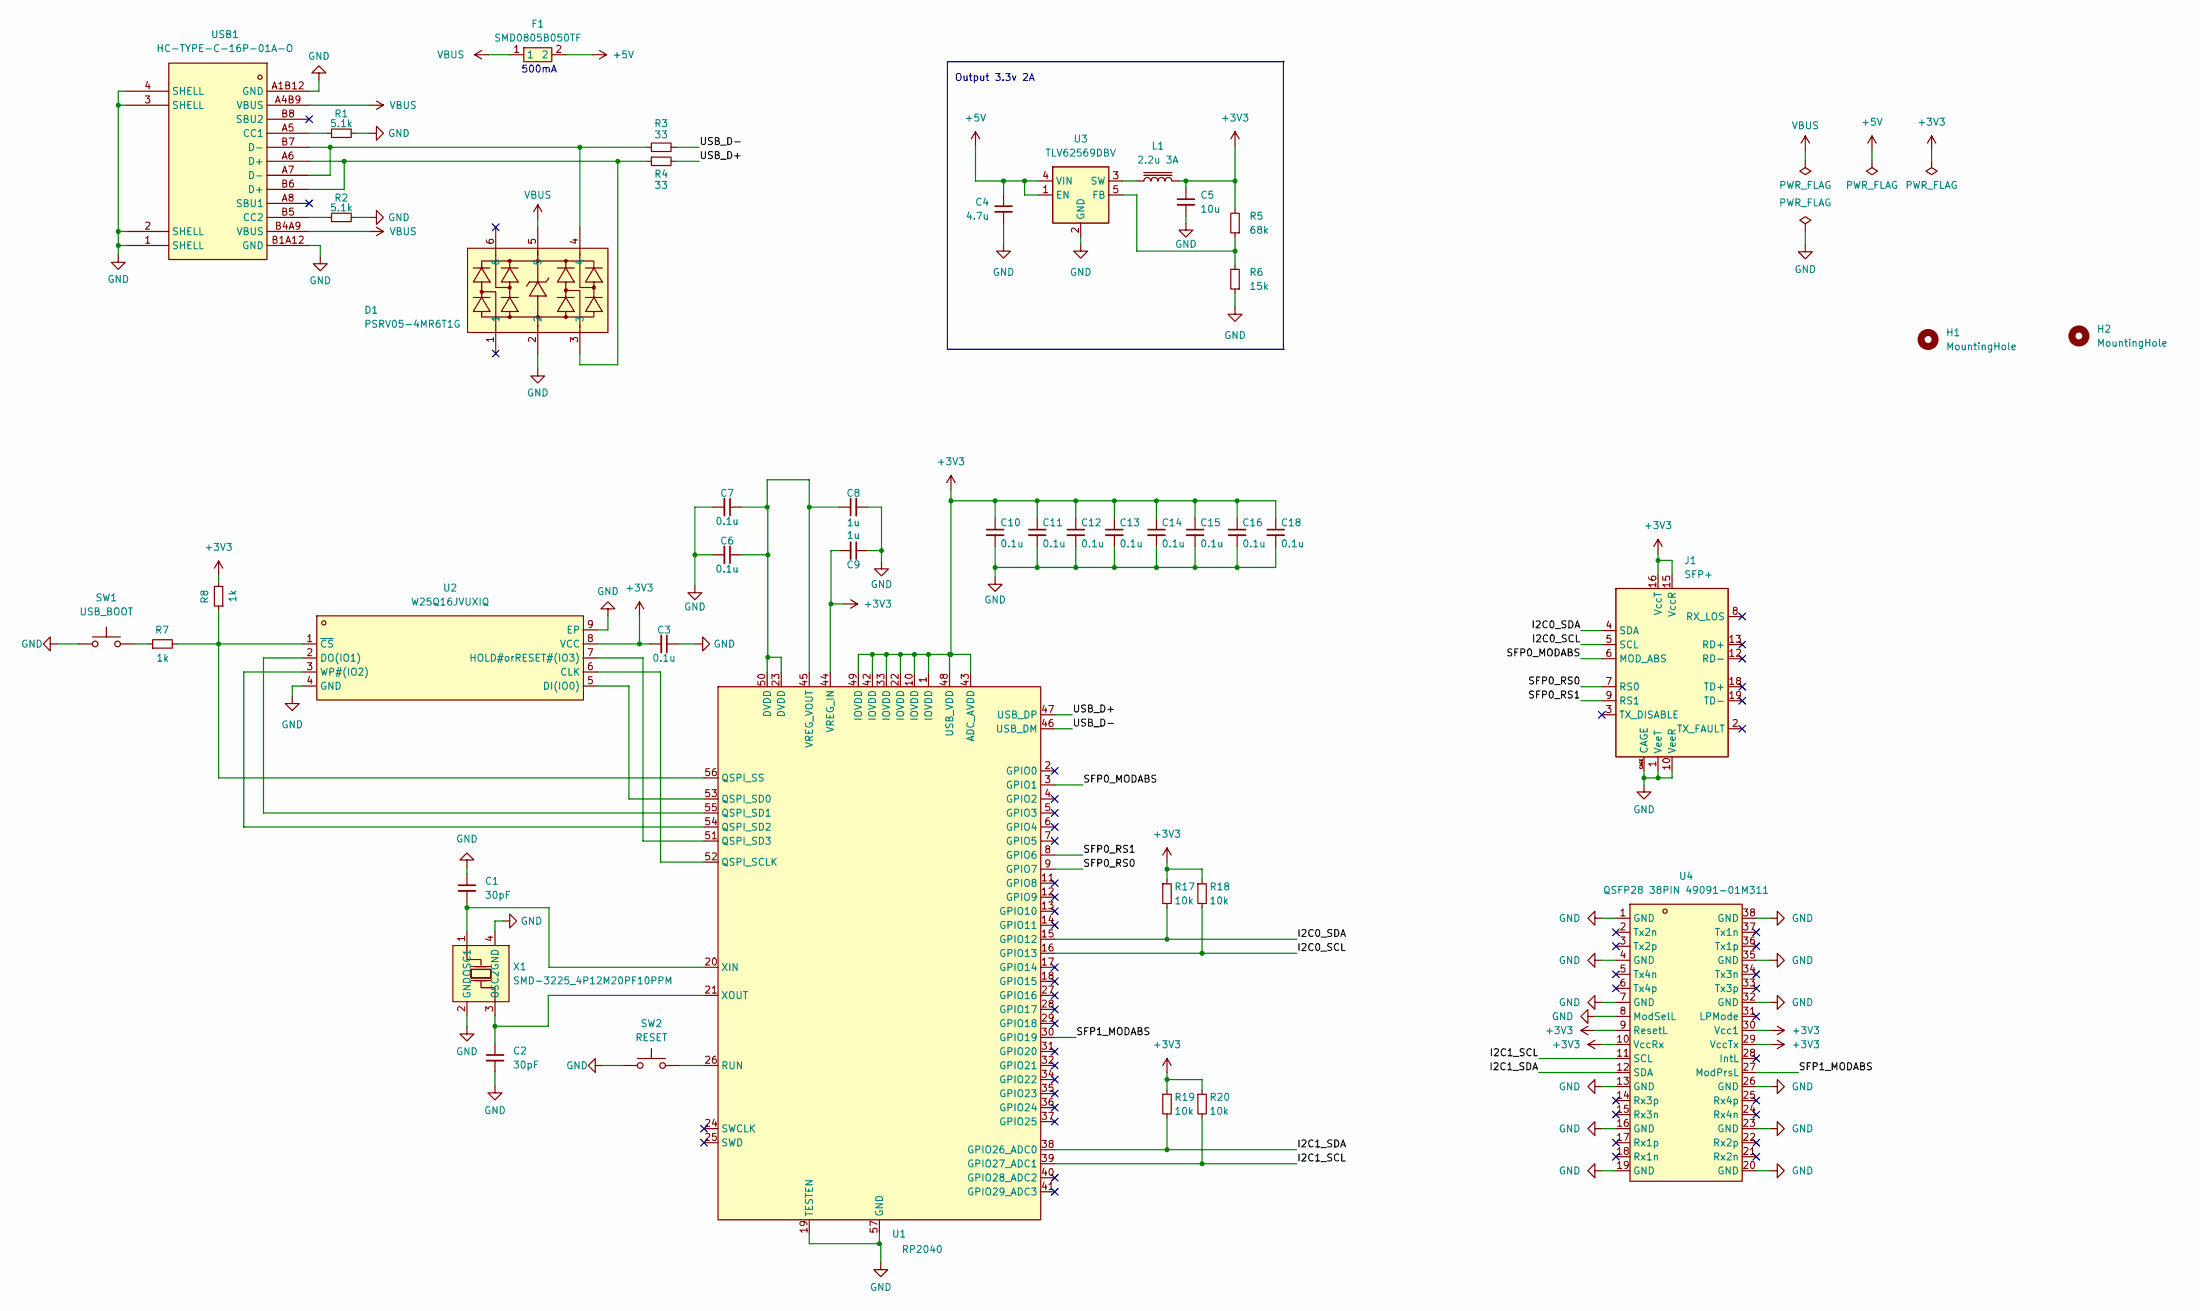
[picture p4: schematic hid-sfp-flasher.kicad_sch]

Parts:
C1, C2: 30pF; C_0603_1608Metric; LCSC Part C1658
C3, C6, C7, C10, C11, C12, C13, C14, C15, C16, C18: 0.1u; C_0402_1005Metric; LCSC Part C1525
C4: 4.7u; C_0603_1608Metric; LCSC C19666
C5: 10u; C_0603_1608Metric; LCSC C19702
C8, C9: 1u; C_0402_1005Metric; LCSC C52923
D1: PSRV05-4MR6T1G; SOT-23-6_L2.9-W1.6-P0.95-LS2.8-BL; LCSC Part C2936987
F1: SMD0805B050TF; F0805; LCSC Part C269104
H1, H2: MountingHole; MountingHole_3.2mm_M3
J1: SFP+; SFP20P
L1: 2.2u 3A; CMLW4030S2R2MST; LCSC C431273
R1, R2: 5.1k; R_0402_1005Metric; LCSC Part C25905
R3, R4: 33; R_0402_1005Metric; LCSC Part C25105
R5: 68k; R_0603_1608Metric; LCSC C23231
R6: 15k; R_0603_1608Metric; LCSC C22809
R7, R8: 1k; R_0402_1005Metric; LCSC C11702
R17, R18, R19, R20: 10k; R_0402_1005Metric; LCSC C25744
SW1: USB_BOOT; SW_SPST_PTS810; LCSC C470427
SW2: RESET; SW_SPST_PTS810; LCSC C470427
U1: RP2040; LQFN-56_L7.0-W7.0-P0.4-EP; LCSC Part C2040
U2: W25Q16JVUXIQ; USON-8_L3.0-W2.0-P0.50-BL-EP; LCSC Part C2843335
U3: TLV62569DBV; SOT-23-5; LCSC C141836
U4: QSFP28 38PIN 49091-01M311; CONN-SMD_38P-P0.80_TE_1551920-2; MPN QSFP28 38PIN 49091-01M311; LCSC Part C50159077
USB1: HC-TYPE-C-16P-01A-O; USB-C-SMD_G-SWITCH_GT-USB-7010EN; LCSC Part C2997434
X1: SMD-3225_4P12M20PF10PPM; CRYSTAL-SMD_4P-L3.2-W2.5-BL; LCSC Part C133334

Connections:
+3V3: C3.2, C5.1, C9.2, C10.1, C11.1, C12.1, C13.1, C14.1, C15.1, C16.1, C18.1, J1.15 (VccR), J1.16 (VccT), L1.2, R5.2, R8.2, R17.1, R18.1, R19.1, R20.1, U1.1 (IOVDD), U1.10 (IOVDD), U1.22 (IOVDD), U1.33 (IOVDD), U1.42 (IOVDD), U1.43 (ADC_AVDD), U1.44 (VREG_IN), U1.48 (USB_VDD), U1.49 (IOVDD), U2.8 (VCC), U4.9 (ResetL), U4.10 (VccRx), U4.29 (VccTx), U4.30 (Vcc1)
+5V: C4.1, F1.2, U3.1 (EN), U3.4 (VIN)
/I2C0_SCL: J1.5 (SCL), R18.2, U1.16 (GPIO13)
/I2C0_SDA: J1.4 (SDA), R17.2, U1.15 (GPIO12)
/I2C1_SCL: R20.2, U1.39 (GPIO27_ADC1), U4.11 (SCL)
/I2C1_SDA: R19.2, U1.38 (GPIO26_ADC0), U4.12 (SDA)
/SFP0_MODABS: J1.6 (MOD_ABS), U1.3 (GPIO1)
/SFP0_RS0: J1.7 (RS0), U1.9 (GPIO7)
/SFP0_RS1: J1.9 (RS1), U1.8 (GPIO6)
/SFP1_MODABS: U1.30 (GPIO19), U4.27 (ModPrsL)
/USB_D+: R4.2, U1.47 (USB_DP)
/USB_D-: R3.2, U1.46 (USB_DM)
GND: C1.1, C2.2, C3.1, C4.2, C5.2, C6.2, C7.2, C8.2, C9.1, C10.2, C11.2, C12.2, C13.2, C14.2, C15.2, C16.2, C18.2, D1.2, J1.1 (VeeT), J1.10 (VeeR), J1.11 (VeeR), J1.14 (VeeR), J1.17 (VeeT), J1.20 (VeeT), J1.CAGE, R1.2, R2.2, R6.1, SW1.2, SW2.2, U1.19 (TESTEN), U1.57 (GND), U2.4 (GND), U2.9 (EP), U3.2 (GND), U4.1 (GND), U4.4 (GND), U4.7 (GND), U4.8 (ModSelL), U4.13 (GND), U4.16 (GND), U4.19 (GND), U4.20 (GND), U4.23 (GND), U4.26 (GND), U4.32 (GND), U4.35 (GND), U4.38 (GND), USB1.1 (SHELL), USB1.2 (SHELL), USB1.3 (SHELL), USB1.4 (SHELL), USB1.A1B12 (GND), USB1.B1A12 (GND), X1.2 (GND), X1.4 (GND)
unnamed: D1.3, R4.1, USB1.A6 (D+), USB1.B6 (D+)
unnamed: D1.4, R3.1, USB1.A7 (D-), USB1.B7 (D-)
unnamed: R7.1, SW1.1
unnamed: U1.52 (QSPI_SCLK), U2.6 (CLK)
unnamed: U1.53 (QSPI_SD0), U2.5 (DI(IO0))
unnamed: U1.55 (QSPI_SD1), U2.2 (DO(IO1))
unnamed: U1.54 (QSPI_SD2), U2.3 (WP#(IO2))
unnamed: U1.51 (QSPI_SD3), U2.7 (HOLD#orRESET#(IO3))
unnamed: R7.2, R8.1, U1.56 (QSPI_SS), U2.1 (~CS)
unnamed: SW2.1, U1.26 (RUN)
unnamed: C6.1, C7.1, C8.1, U1.23 (DVDD), U1.45 (VREG_VOUT), U1.50 (DVDD)
unnamed: C1.2, U1.20 (XIN), X1.1 (OSC1)
unnamed: C2.1, U1.21 (XOUT), X1.3 (OSC2)
unnamed: R5.1, R6.2, U3.5 (FB)
unnamed: L1.1, U3.3 (SW)
unnamed: R1.1, USB1.A5 (CC1)
unnamed: R2.1, USB1.B5 (CC2)
VBUS: D1.5, F1.1, USB1.A4B9 (VBUS), USB1.B4A9 (VBUS)

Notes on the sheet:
Output 3.3v 2A
500mA

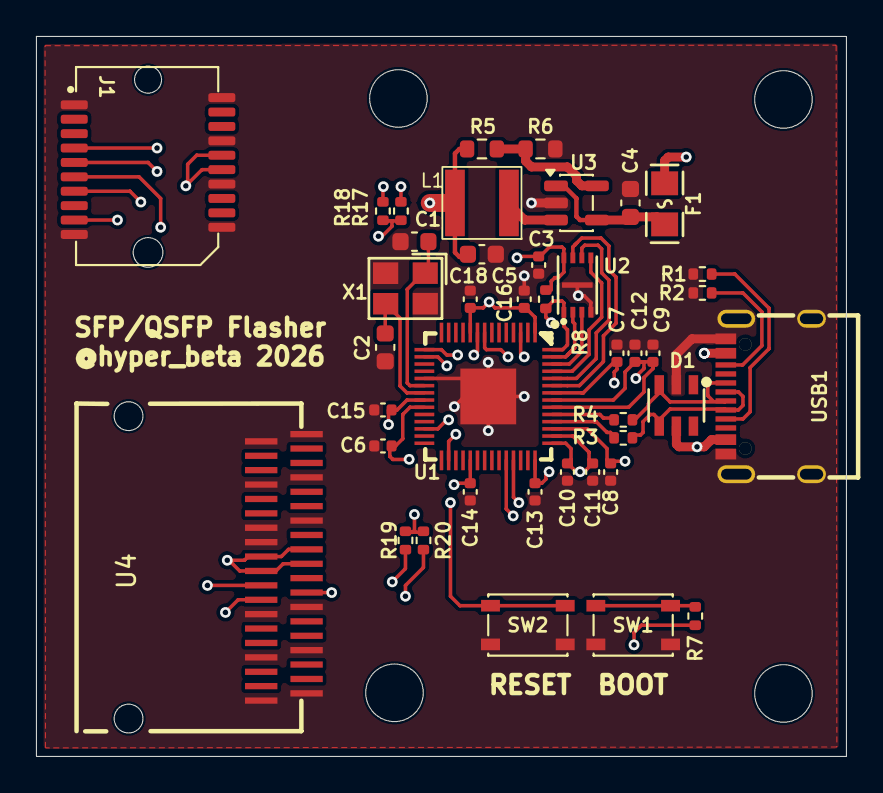
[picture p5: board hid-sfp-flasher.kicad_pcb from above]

Board: 4 copper layers, 45.0 x 40.0 mm, 45 parts (0 on the bottom side), 31 nets.

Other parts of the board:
H1#2, H1#3: MountingHole; MountingHole_3.2mm_M3

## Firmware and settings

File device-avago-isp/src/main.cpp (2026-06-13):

#include <Arduino.h>
#include <Wire.h>
#include <Adafruit_TinyUSB.h>

// ---------------------------------------------------------------------------
// Avago 解析/書換用 ゲートウェイ (WebHID <-> I2C + AVR ISP)
//
// device-src の汎用ゲートウェイに、Avago/Broadcom 内蔵 ATmega を SPI で
// シリアルプログラミング(ISP)する機能を足した「専用ボード用」ファーム。
// 既存ファームとは独立。bus0 ピンもこのボードの配線に合わせてある。
//
// 用途(方式A): ISP で内部 EEPROM 0x01FF=0x55 を 1 バイト書く → 電源再投入で
// プログラミングモード起動 → 0x58 隠し mailbox が I2C で生き、EEPROM を書ける。
//
// 専用ボード配線 (VCC/GND 以外は SFPピン番号 = GPIO番号):
//   MOSI = SFP pin4  -> GP4   (I2C bus0 SDA と共用)
//   SCK  = SFP pin5  -> GP5   (I2C bus0 SCL と共用)
//   MISO = SFP pin9  -> GP9
//   RST  = SFP pin15 -> GP15
//   VCC  = SFP pin16 -> 3V3,   GND = SFP pin1
//
// OUT(64B): [0]seq [1]cmd [2]bus [3]addr [4]reg [5]len [6..]data
// IN (64B): [0]seq [1]status [2]len [3..]data
// ---------------------------------------------------------------------------

#define REPORT_LEN 64
#define FW_MAJOR   2
#define FW_MINOR   0   // 2.0: Avago ISP 専用ファーム

// コマンド
enum {
  CMD_PING  = 0x00,
  CMD_READ  = 0x01,
  CMD_WRITE = 0x02,
  CMD_SCAN  = 0x03,
  // AVR ISP (内蔵 ATmega を SPI でシリアルプログラミング)
  CMD_ISP_BEGIN = 0x10,  // RESET Low → Programming Enable。応答 data[0..2]=signature
  CMD_ISP_XFER  = 0x11,  // len バイトを全二重 SPI 転送し、受信 len バイトを返す
  CMD_ISP_END   = 0x12,  // RESET 解放 → I2C(bus0) 復帰
};

// ステータス
enum {
  ST_OK     = 0x00,
  ST_NACK   = 0x01,
  ST_BADARG = 0x02,
  ST_TOOBIG = 0x03,
};

static const uint8_t MAX_READ  = REPORT_LEN - 3; // =61
static const uint8_t MAX_WRITE = REPORT_LEN - 6; // =58

// --- I2C bus0 ピン (このボードの配線。SFP pin4/5 = GP4/GP5) ---
#define BUS0_SDA   4
#define BUS0_SCL   5

// --- ISP 用ピン (RP2040 GPIO = SFP コネクタピン番号) ---
#define ISP_MOSI   4    // SFP pin4  (I2C SDA と共用)
#define ISP_SCK    5    // SFP pin5  (I2C SCL と共用)
#define ISP_MISO   9    // SFP pin9
#define ISP_RST    15   // SFP pin15
#define ISP_DLY_US 5    // SCK 半周期 ≒ 100kHz (ターゲット内蔵8MHz の 1/4 未満)

// HIDレポートディスクリプタ: ベンダ定義(usage page 0xFF00)の64バイトIN/OUT
uint8_t const desc_hid_report[] = {
  TUD_HID_REPORT_DESC_GENERIC_INOUT(REPORT_LEN)
};

Adafruit_USBD_HID usb_hid;

static volatile bool g_pending = false;
static uint8_t       g_req[REPORT_LEN];

static TwoWire *busPtr(uint8_t bus) {
  return (bus == 1) ? &Wire1 : &Wire;
}

static void setReportCb(uint8_t report_id, hid_report_type_t report_type,
                        uint8_t const *buffer, uint16_t bufsize) {
  (void)report_id;
  (void)report_type;
  if (g_pending) return;
  uint16_t n = (bufsize < REPORT_LEN) ? bufsize : REPORT_LEN;
  memset(g_req, 0, sizeof(g_req));
  memcpy(g_req, buffer, n);
  g_pending = true;
}

// ---------------- I2C ----------------
static uint8_t i2cRead(uint8_t bus, uint8_t addr, uint8_t reg, uint8_t len, uint8_t *out) {
  TwoWire *w = busPtr(bus);
  w->beginTransmission(addr);
  w->write(reg);
  if (w->endTransmission(true) != 0) return ST_NACK;
  uint8_t got = w->requestFrom((int)addr, (int)len);
  for (uint8_t i = 0; i < got && i < len; i++) out[i] = w->read();
  return (got == len) ? ST_OK : ST_NACK;
}

static uint8_t i2cWrite(uint8_t bus, uint8_t addr, uint8_t reg, uint8_t len, const uint8_t *data) {
  TwoWire *w = busPtr(bus);
  w->beginTransmission(addr);
  w->write(reg);
  for (uint8_t i = 0; i < len; i++) w->write(data[i]);
  uint8_t e = w->endTransmission(true);
  delay(6);
  return (e == 0) ? ST_OK : ST_NACK;
}

static uint8_t i2cScan(uint8_t bus, uint8_t *out, uint8_t maxOut) {
  TwoWire *w = busPtr(bus);
  uint8_t n = 0;
  for (uint8_t a = 0x08; a <= 0x77 && n < maxOut; a++) {
    w->beginTransmission(a);
    if (w->endTransmission(true) == 0) out[n++] = a;
  }
  return n;
}

// ---------------- AVR ISP ----------------
// SPI mode0 ビットバング。SCK アイドル Low、立上りで MISO を採取(MSB first)。
// 通常時 PB3/PB4/PB5 は Hi-Z 入力なので I2C 線(GP4/GP5)と相乗りできる。
static uint8_t ispByte(uint8_t out) {
  uint8_t in = 0;
  for (int8_t i = 7; i >= 0; i--) {
    digitalWrite(ISP_MOSI, (out >> i) & 1);
    delayMicroseconds(ISP_DLY_US);
    digitalWrite(ISP_SCK, HIGH);
    delayMicroseconds(ISP_DLY_US);
    in = (in << 1) | (digitalRead(ISP_MISO) & 1);
    digitalWrite(ISP_SCK, LOW);
  }
  return in;
}

// Programming Enable まで実施。成功(0x53 エコー)で true
static bool ispBegin() {
  Wire.end();                               // GP4/GP5 を I2C から解放
  pinMode(ISP_MISO, INPUT);
  pinMode(ISP_MOSI, OUTPUT);
  pinMode(ISP_SCK,  OUTPUT);
  pinMode(ISP_RST,  OUTPUT);
  digitalWrite(ISP_MOSI, LOW);
  digitalWrite(ISP_SCK,  LOW);              // 突入前に SCK = Low
  digitalWrite(ISP_RST,  HIGH); delay(1);
  digitalWrite(ISP_RST,  LOW);  delay(25);  // RESET 正パルス → Low 保持(>20ms)
  uint8_t c[4] = {0xAC, 0x53, 0x00, 0x00}, r[4];
  for (uint8_t i = 0; i < 4; i++) r[i] = ispByte(c[i]);
  return r[2] == 0x53;
}

// RESET 解放 → AVR 通常起動 → I2C(bus0) 再初期化
static void ispEnd() {
  pinMode(ISP_RST,  INPUT);                 // モジュール側プルアップで Reset 解除
  pinMode(ISP_MOSI, INPUT);
  pinMode(ISP_SCK,  INPUT);
  Wire.setSDA(BUS0_SDA);
  Wire.setSCL(BUS0_SCL);
  Wire.begin();
  Wire.setClock(100000);
}

// ---------------- リクエスト処理 ----------------
static void processRequest(const uint8_t *req) {
  uint8_t resp[REPORT_LEN];
  memset(resp, 0, sizeof(resp));

  const uint8_t seq  = req[0];
  const uint8_t cmd  = req[1];
  const uint8_t bus  = req[2];
  const uint8_t addr = req[3];
  const uint8_t reg  = req[4];
  const uint8_t len  = req[5];

  resp[0] = seq;
  resp[1] = ST_OK;
  resp[2] = 0;

  if (bus > 1 && cmd != CMD_PING && cmd < 0x10) {
    resp[1] = ST_BADARG;
  } else {
    switch (cmd) {
      case CMD_PING:
        resp[2] = 2;
        resp[3] = FW_MAJOR;
        resp[4] = FW_MINOR;
        break;

      case CMD_READ:
        if (len > MAX_READ) {
          resp[1] = ST_TOOBIG;
        } else {
          resp[1] = i2cRead(bus, addr, reg, len, &resp[3]);
          resp[2] = (resp[1] == ST_OK) ? len : 0;
        }
        break;

      case CMD_WRITE:
        if (len > MAX_WRITE) {
          resp[1] = ST_TOOBIG;
        } else {
          resp[1] = i2cWrite(bus, addr, reg, len, &req[6]);
          resp[2] = 0;
        }
        break;

      case CMD_SCAN:
        resp[2] = i2cScan(bus, &resp[3], MAX_READ);
        break;

      case CMD_ISP_BEGIN: {
        bool ok = ispBegin();
        uint8_t c[4], r[4];
        for (uint8_t i = 0; i < 3; i++) {        // signature 3バイト
          c[0] = 0x30; c[1] = 0x00; c[2] = i; c[3] = 0x00;
          for (uint8_t k = 0; k < 4; k++) r[k] = ispByte(c[k]);
          resp[3 + i] = r[3];
        }
        resp[1] = ok ? ST_OK : ST_NACK;
        resp[2] = 3;
        break;
      }

      case CMD_ISP_XFER:
        if (len > MAX_WRITE) {
          resp[1] = ST_TOOBIG;
        } else {
          for (uint8_t i = 0; i < len; i++) resp[3 + i] = ispByte(req[6 + i]);
          resp[1] = ST_OK;
          resp[2] = len;
        }
        break;

      case CMD_ISP_END:
        ispEnd();
        resp[1] = ST_OK;
        resp[2] = 0;
        break;

      default:
        resp[1] = ST_BADARG;
        break;
    }
  }

  uint32_t t0 = millis();
  while (!usb_hid.ready() && (millis() - t0) < 50) delay(1);
  usb_hid.sendReport(0, resp, REPORT_LEN);
}

void setup() {
  usb_hid.setPollInterval(2);
  usb_hid.setReportDescriptor(desc_hid_report, sizeof(desc_hid_report));
  usb_hid.setReportCallback(NULL, setReportCb);
  usb_hid.begin();

  Serial.begin(115200);

  Wire.setSDA(BUS0_SDA);
  Wire.setSCL(BUS0_SCL);
  Wire.begin();
  Wire.setClock(100000);

  Wire1.setSDA(26);
  Wire1.setSCL(27);
  Wire1.begin();
  Wire1.setClock(100000);

  uint32_t t0 = millis();
  while (!TinyUSBDevice.mounted() && (millis() - t0) < 3000) delay(10);
  Serial.println("\nAvago ISP gateway ready (bus0=4/5, bus1=26/27, ISP=4/5/9/15)");
}

void loop() {
  if (g_pending) {
    processRequest(g_req);
    g_pending = false;
  }
}

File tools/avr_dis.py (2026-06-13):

#!/usr/bin/env python3
"""Minimal AVR disassembler for analyzing the Cisco/Avago SFP MCU firmware.
Covers the common ATmega instruction subset well enough to read control flow,
I/O register access (TWI/I2C), and EEPROM access.
Usage: python avr_dis.py <bin> [start_word] [end_word]
"""
import sys

def u16(b, i):
    return b[i] | (b[i+1] << 8)

# I/O register names (ATmega88/168/328 style extended I/O for TWI). We map
# both low I/O (in/out, 0x00-0x3f) and data-space addrs (0x20 + io).
IO = {
    0x23:"PINB",0x24:"DDRB",0x25:"PORTB",0x26:"PINC",0x27:"DDRC",0x28:"PORTC",
    0x29:"PIND",0x2a:"DDRD",0x2b:"PORTD",
    0x35:"TIFR0",0x36:"TIFR1",0x37:"TIFR2",
    0x3a:"GPIOR1",0x3b:"GPIOR2",0x3c:"PCIFR",0x3d:"EIFR",0x3e:"EIMSK",0x3f:"GPIOR0",
    0x40:"EECR",0x41:"EEDR",0x42:"EEARL",0x43:"EEARH",0x44:"GTCCR",0x45:"TCCR0A",
    0x46:"TCCR0B",0x47:"TCNT0",0x48:"OCR0A",0x49:"OCR0B",
    0x4c:"SPCR",0x4d:"SPSR",0x4e:"SPDR",0x50:"ACSR",
    0x53:"SMCR",0x54:"MCUSR",0x55:"MCUCR",0x57:"SPMCSR",
    0x5d:"SPL",0x5e:"SPH",0x5f:"SREG",
    0x60:"WDTCSR",0x61:"CLKPR",0x64:"PRR",0x66:"OSCCAL",
    0x68:"PCICR",0x69:"EICRA",0x6b:"PCMSK0",0x6c:"PCMSK1",0x6d:"PCMSK2",
    0x6e:"TIMSK0",0x6f:"TIMSK1",0x70:"TIMSK2",
    0x78:"ADCL",0x79:"ADCH",0x7a:"ADCSRA",0x7b:"ADCSRB",0x7c:"ADMUX",
    0x7e:"DIDR0",0x7f:"DIDR1",
    0x80:"TCCR1A",0x81:"TCCR1B",0x82:"TCCR1C",0x84:"TCNT1L",0x85:"TCNT1H",
    0x86:"ICR1L",0x87:"ICR1H",0x88:"OCR1AL",0x89:"OCR1AH",0x8a:"OCR1BL",0x8b:"OCR1BH",
    0xb0:"TCCR2A",0xb1:"TCCR2B",0xb2:"TCNT2",0xb3:"OCR2A",0xb4:"OCR2B",0xb6:"ASSR",
    0xb8:"TWBR",0xb9:"TWSR",0xba:"TWAR",0xbb:"TWDR",0xbc:"TWCR",0xbd:"TWAMR",
    0xc0:"UCSR0A",0xc1:"UCSR0B",0xc2:"UCSR0C",0xc4:"UBRR0L",0xc5:"UBRR0H",0xc6:"UDR0",
}

def ioname(a, dataspace=False):
    addr = a + 0x20 if not dataspace else a
    return IO.get(addr, None)

def dis(b, start=0, end=None):
    n = len(b)
    if end is None: end = n // 2
    out = []
    i = start * 2
    while i < end * 2 and i + 1 < n:
        w = u16(b, i)
        addr = i // 2
        nextw = u16(b, i+2) if i+2 < n else 0
        size = 1
        s = ".dw 0x%04x" % w

        # 32-bit ops first
        if (w & 0xfe0e) == 0x940c:  # jmp
            k = ((w >> 4) & 0x1f) << 1 | (w & 1)
            k = (k << 16) | nextw
            s = "jmp  0x%05x" % k; size = 2
        elif (w & 0xfe0e) == 0x940e:  # call
            k = ((w >> 4) & 0x1f) << 1 | (w & 1)
            k = (k << 16) | nextw
            s = "call 0x%05x" % k; size = 2
        elif (w & 0xfe0f) == 0x9000:  # lds Rd,k
            d = (w >> 4) & 0x1f
            s = "lds  r%d, 0x%04x" % (d, nextw); size = 2
        elif (w & 0xfe0f) == 0x9200:  # sts k,Rr
            d = (w >> 4) & 0x1f
            nm = IO.get(nextw, None)
            tgt = ("0x%04x" % nextw) + (" ;%s" % nm if nm else "")
            s = "sts  %s, r%d" % (tgt, d); size = 2
        # rjmp / rcall
        elif (w & 0xf000) == 0xc000:
            k = w & 0xfff
            if k >= 0x800: k -= 0x1000
            s = "rjmp 0x%05x" % (addr + 1 + k)
        elif (w & 0xf000) == 0xd000:
            k = w & 0xfff
            if k >= 0x800: k -= 0x1000
            s = "rcall 0x%05x" % (addr + 1 + k)
        # branches (BRBS/BRBC)
        elif (w & 0xf800) == 0xf000 or (w & 0xf800) == 0xf400:
            k = (w >> 3) & 0x7f
            if k >= 0x40: k -= 0x80
            sbit = w & 7
            setclr = (w & 0xfc00) == 0xf000
            names = {0:"cs/lo",1:"eq",2:"mi",3:"vs",4:"lt",5:"hs",6:"ts",7:"ie"}
            cc = {0:"brcs",1:"breq",2:"brmi",3:"brvs",4:"brlt",5:"brhs",6:"brts",7:"brie"} if setclr \
                else {0:"brcc",1:"brne",2:"brpl",3:"brvc",4:"brge",5:"brlo",6:"brtc",7:"brid"}
            s = "%s 0x%05x" % (cc[sbit], addr + 1 + k)
        # ldi
        elif (w & 0xf000) == 0xe000:
            d = ((w >> 4) & 0xf) + 16
            k = ((w >> 4) & 0xf0) | (w & 0xf)
            s = "ldi  r%d, 0x%02x" % (d, k)
        # in / out
        elif (w & 0xf800) == 0xb000:  # in
            d = (w >> 4) & 0x1f
            a = ((w >> 5) & 0x30) | (w & 0xf)
            nm = ioname(a); s = "in   r%d, 0x%02x%s" % (d, a, (" ;%s"%nm if nm else ""))
        elif (w & 0xf800) == 0xb800:  # out
            r = (w >> 4) & 0x1f
            a = ((w >> 5) & 0x30) | (w & 0xf)
            nm = ioname(a); s = "out  0x%02x, r%d%s" % (a, r, (" ;%s"%nm if nm else ""))
        # sbi/cbi/sbic/sbis
        elif (w & 0xff00) == 0x9a00:
            a=(w>>3)&0x1f; bb=w&7; nm=ioname(a); s="sbi  0x%02x, %d%s"%(a,bb,(" ;%s"%nm if nm else ""))
        elif (w & 0xff00) == 0x9800:
            a=(w>>3)&0x1f; bb=w&7; nm=ioname(a); s="cbi  0x%02x, %d%s"%(a,bb,(" ;%s"%nm if nm else ""))
        elif (w & 0xff00) == 0x9b00:
            a=(w>>3)&0x1f; bb=w&7; nm=ioname(a); s="sbis 0x%02x, %d%s"%(a,bb,(" ;%s"%nm if nm else ""))
        elif (w & 0xff00) == 0x9900:
            a=(w>>3)&0x1f; bb=w&7; nm=ioname(a); s="sbic 0x%02x, %d%s"%(a,bb,(" ;%s"%nm if nm else ""))
        # sbrc/sbrs
        elif (w & 0xfe08) == 0xfc00:
            d=(w>>4)&0x1f; bb=w&7; s="sbrc r%d, %d"%(d,bb)
        elif (w & 0xfe08) == 0xfe00:
            d=(w>>4)&0x1f; bb=w&7; s="sbrs r%d, %d"%(d,bb)
        # cpi
        elif (w & 0xf000) == 0x3000:
            d=((w>>4)&0xf)+16; k=((w>>4)&0xf0)|(w&0xf); s="cpi  r%d, 0x%02x"%(d,k)
        # andi/ori/subi/sbci
        elif (w & 0xf000) == 0x7000:
            d=((w>>4)&0xf)+16; k=((w>>4)&0xf0)|(w&0xf); s="andi r%d, 0x%02x"%(d,k)
        elif (w & 0xf000) == 0x6000:
            d=((w>>4)&0xf)+16; k=((w>>4)&0xf0)|(w&0xf); s="ori  r%d, 0x%02x"%(d,k)
        elif (w & 0xf000) == 0x5000:
            d=((w>>4)&0xf)+16; k=((w>>4)&0xf0)|(w&0xf); s="subi r%d, 0x%02x"%(d,k)
        elif (w & 0xf000) == 0x4000:
            d=((w>>4)&0xf)+16; k=((w>>4)&0xf0)|(w&0xf); s="sbci r%d, 0x%02x"%(d,k)
        # 2-reg ALU
        elif (w & 0xfc00) == 0x1c00: s=alu2("adc",w)
        elif (w & 0xfc00) == 0x0c00: s=alu2("add",w)
        elif (w & 0xfc00) == 0x2000: s=alu2("and",w)
        elif (w & 0xfc00) == 0x1400: s=alu2("cp",w)
        elif (w & 0xfc00) == 0x0400: s=alu2("cpc",w)
        elif (w & 0xfc00) == 0x1000: s=alu2("cpse",w)
        elif (w & 0xfc00) == 0x2400: s=alu2("eor",w)
        elif (w & 0xfc00) == 0x2c00: s=alu2("mov",w)
        elif (w & 0xfc00) == 0x2800: s=alu2("or",w)
        elif (w & 0xfc00) == 0x0800: s=alu2("sbc",w)
        elif (w & 0xfc00) == 0x1800: s=alu2("sub",w)
        elif (w & 0xfc00) == 0x9c00: s=alu2("mul",w)
        # movw
        elif (w & 0xff00) == 0x0100:
            d=((w>>4)&0xf)*2; r=(w&0xf)*2; s="movw r%d, r%d"%(d,r)
        # single-reg
        elif (w & 0xfe0f) == 0x9403: s="inc  r%d"%((w>>4)&0x1f)
        elif (w & 0xfe0f) == 0x940a: s="dec  r%d"%((w>>4)&0x1f)
        elif (w & 0xfe0f) == 0x9400: s="com  r%d"%((w>>4)&0x1f)
        elif (w & 0xfe0f) == 0x9401: s="neg  r%d"%((w>>4)&0x1f)
        elif (w & 0xfe0f) == 0x9405: s="asr  r%d"%((w>>4)&0x1f)
        elif (w & 0xfe0f) == 0x9406: s="lsr  r%d"%((w>>4)&0x1f)
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

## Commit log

2026-06-04 device init
2026-06-05 AvagoとかFinのパスワードつきとか
2026-06-13 Avago用のISP対応
2026-06-20 add kicad prj
    [BOM-hid-sfp-flasher.csv, SFP20P SFP&SFP &SFP28 1X1连接器 模型3D.STEP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]
2026-06-20 ケースのモデル
